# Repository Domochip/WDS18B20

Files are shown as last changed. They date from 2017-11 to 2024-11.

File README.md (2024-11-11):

# WDS18B20

This project allows you to build a wide DS18B20 sensors network **over a house**  
It uses :  

- a D1 Mini (ESP8266)
- some DS18B20 sensors
- a customized Tasmota firmware

## Build your 1-Wire bus

In order to get a wide 1-Wire bus (one that cover a house), Dallas provides some recommendations into their application note AN148.

This project use the Improved Interface bellow that is able to support a **200 meters long bus**:

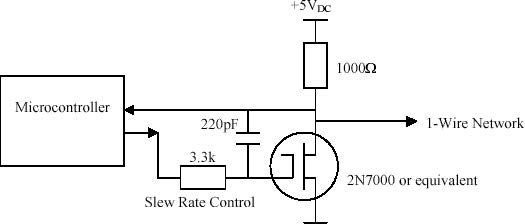
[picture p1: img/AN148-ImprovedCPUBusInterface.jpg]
Dallas AN148 ImprovedCPUBusInterface schema


This one requires a pin for reading the bus state and another one as output to drive the bus low : I named it the "Dual Pin OneWire"

**Warning : If you build a large 1 Wire bus inside your house, keep in mind that some voltage may appear on this one by induction. You need to have a good knowledge about electricity and associated risks!!!**

## Build your WDS18B20

All files are inside `schematic` subfolder and has been designed with KiCad

### Schematic

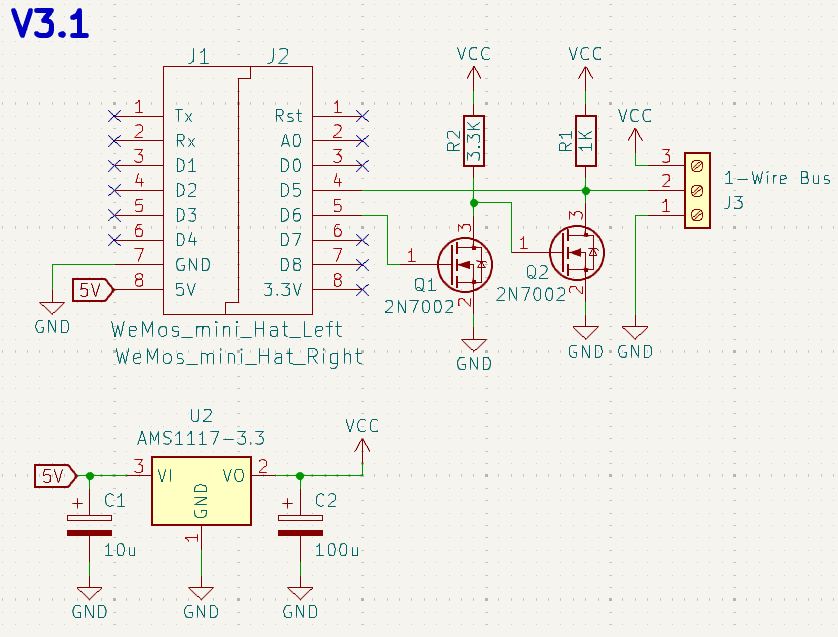
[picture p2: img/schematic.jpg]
WDS18B20 schematic


### PCB

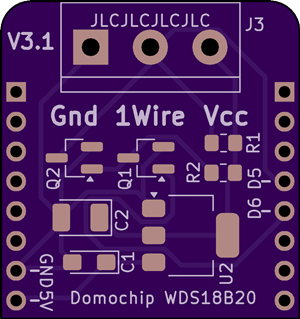
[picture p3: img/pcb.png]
WDS18B20 PCB
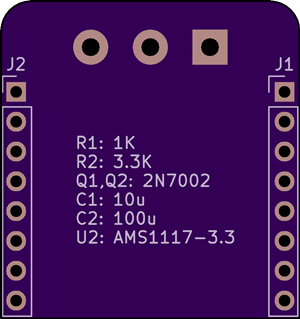
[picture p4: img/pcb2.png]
WDS18B20 PCB2


### Print your box

Box project (Fusion 360) and STL files can be found into `box` folder

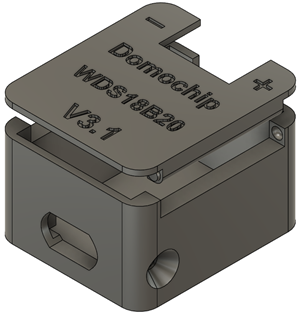
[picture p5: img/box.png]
WDS18B20 Box


## Code/Compile/Flash

A specific variation in the Tasmota code needs to be done before compilation.  
**Compile it yourself** by following bellow steps **OR precompiled binaries are available in Releases**.

### Prepare compilation environment

You need to follow Tasmota guides to be ready for compilation:  
<https://tasmota.github.io/docs/Compile-your-build/>

### Code

You need to edit `tasmota/tasmota_xsns_sensor/xsns_05_ds18x20.ino` file

1. enable `#define DS18x20_USE_ID_AS_NAME` by removing the '//'
2. replace `#define DS18X20_MAX_SENSORS  8` by `#define DS18X20_MAX_SENSORS  16`
3. For PCB 3.0 and lower
   1. replace all `digitalWrite(DS18X20Data.pin_out, HIGH);` by `digitalWrite(DS18X20Data.pin_out, newLOW);`
   2. replace all `digitalWrite(DS18X20Data.pin_out, LOW);` by `digitalWrite(DS18X20Data.pin_out, HIGH);`
   3. replace all `digitalWrite(DS18X20Data.pin_out, newLOW);` by `digitalWrite(DS18X20Data.pin_out, LOW);`
4. save
5. Compile Tasmota
6. Rename resulting tasmota.bin to tasmota-WDS18B20-12.1.0.bin

### Flash

You will find all available tools to flash tasmota in the official documentation:  
<https://tasmota.github.io/docs/Getting-Started/#needed-software>

## Run

### Tasmota Configuration

You need to apply this Template:  
`{"NAME":"WDS18B20","GPIO":[0,0,0,0,0,0,0,0,1344,0,1312,0,0,0],"FLAG":0,"BASE":18,"CMND":"Module 0|TelePeriod 60"}`

To change number of digit after the dot on reported temperatures:  
`TempRes 2`

To Enable arithmetic mean over teleperiod:  
`SetOption126 1`

For more details, please refer to the Tasmota documentation:  
<https://tasmota.github.io/docs/DS18x20>

## And finally

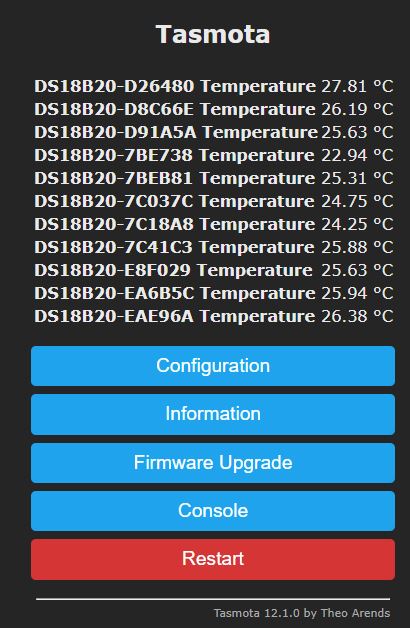
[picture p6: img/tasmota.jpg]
WDS18B20 tasmota


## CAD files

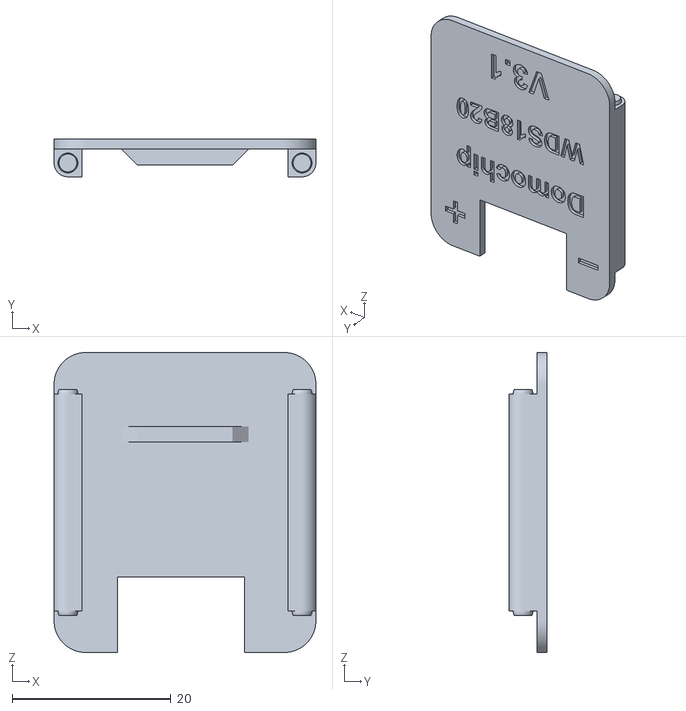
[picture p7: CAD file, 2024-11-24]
box/WDS18B20 Lid.stl
33.0 x 4.75 x 37.8

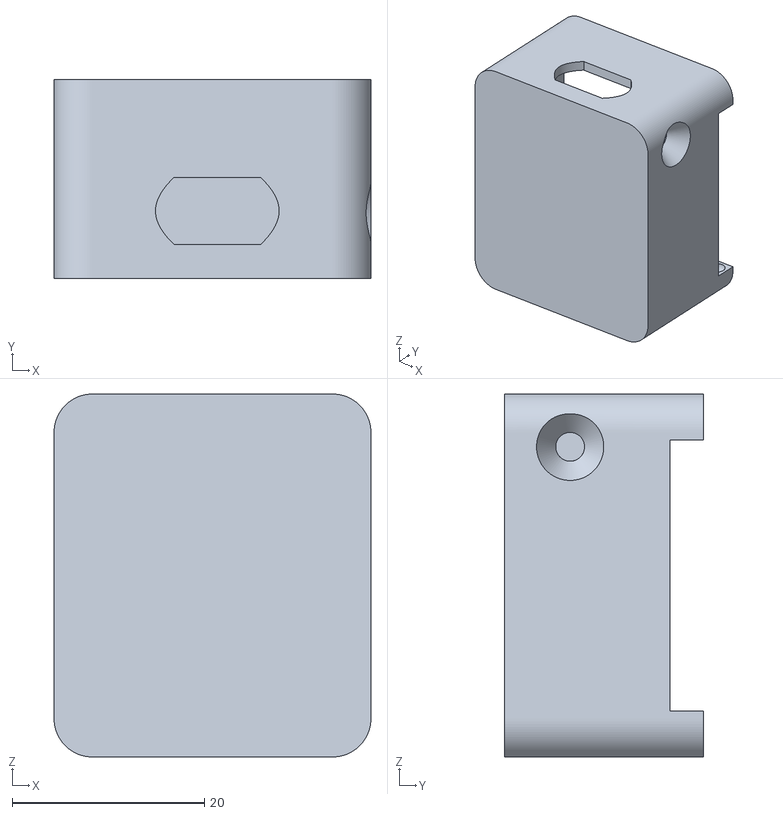
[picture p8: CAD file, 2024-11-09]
box/WDS18B20 Box.stl
33.0 x 20.8 x 37.8

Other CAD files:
box/WDS18B20 v22.f3d

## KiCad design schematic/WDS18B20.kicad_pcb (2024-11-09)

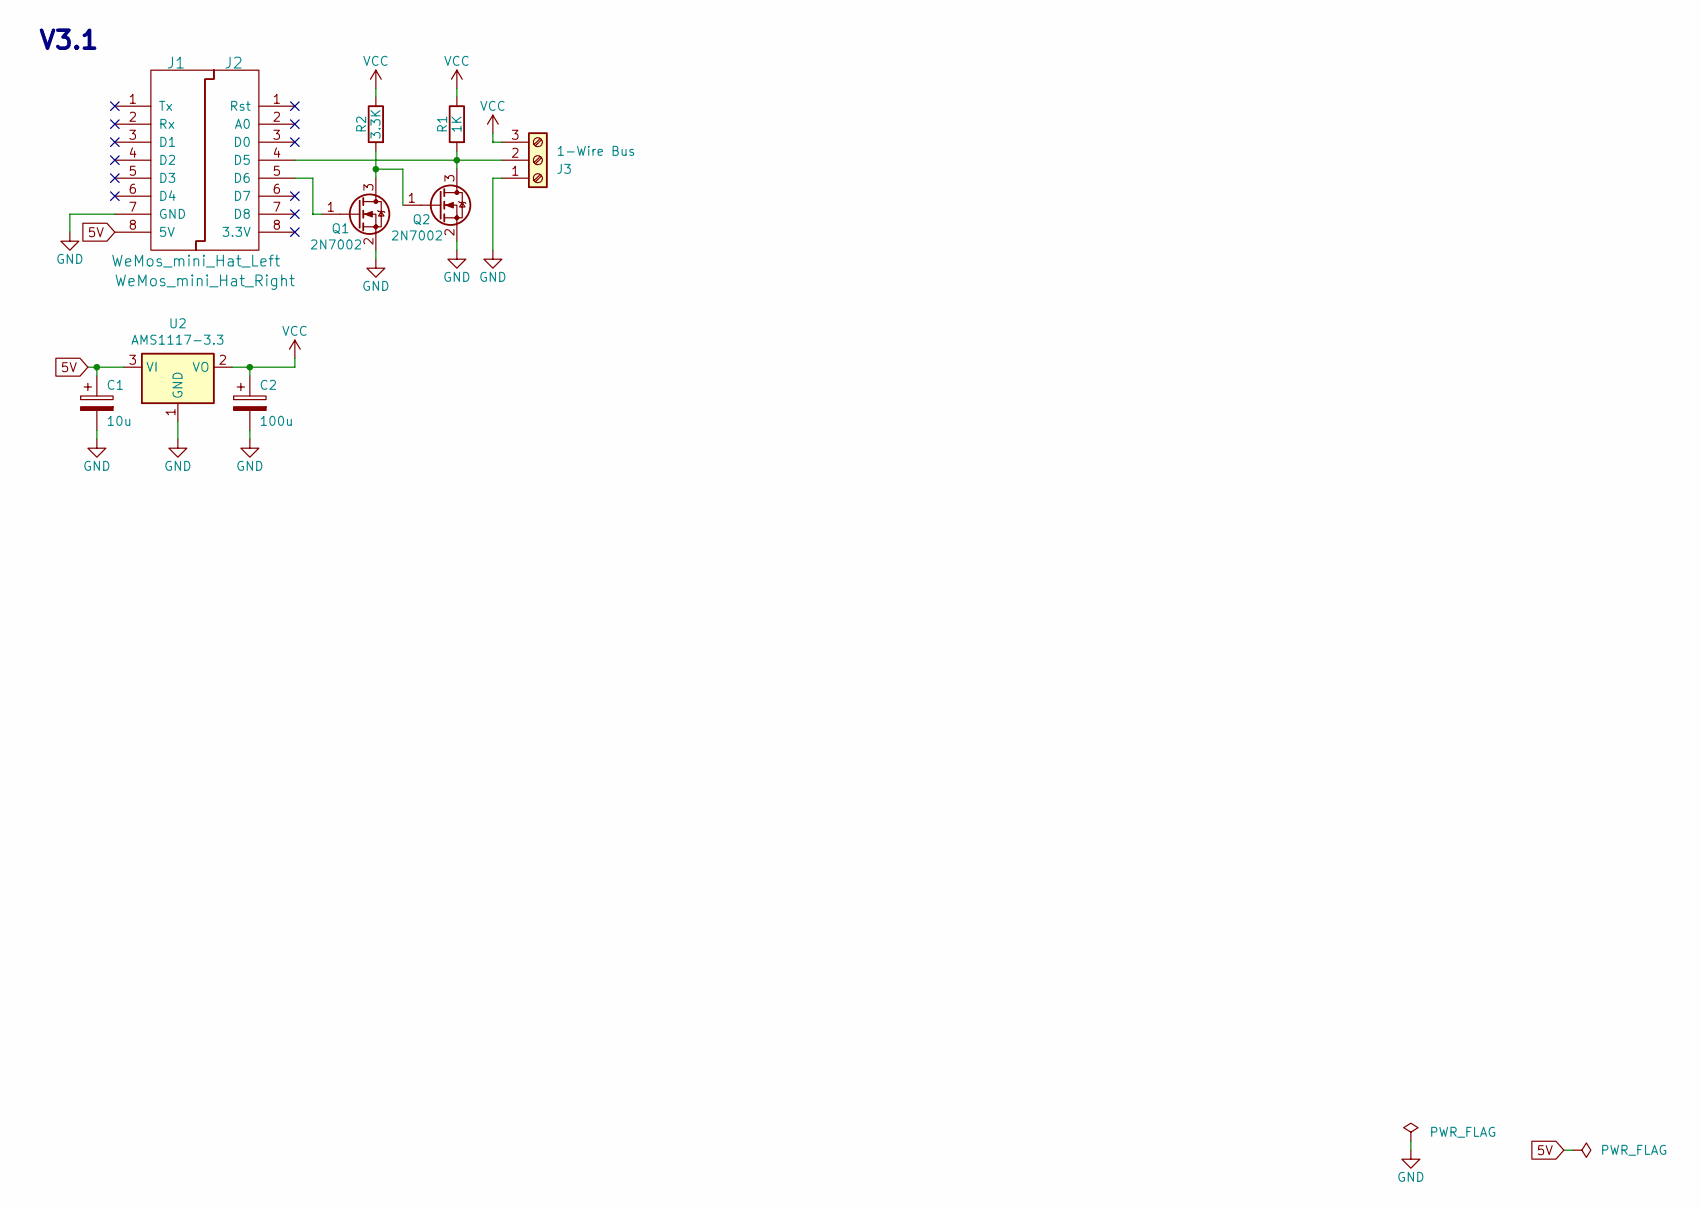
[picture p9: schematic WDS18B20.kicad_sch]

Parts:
C1: 10u; CP_EIA-3216-18_Kemet-A_Pad1.58x1.35mm_HandSolder; LCSC C7171
C2: 100u; CP_EIA-3528-21_Kemet-B_Pad1.50x2.35mm_HandSolder; LCSC C16133
J1: WeMos_mini_Hat_Left; WeMos_D1_mini_Hat_Left; LCSC C7509515
J2: WeMos_mini_Hat_Right; WeMos_D1_mini_Hat_Right; LCSC C7509515
J3: 1-Wire Bus; TerminalBlock_bornier-3_P5.08mm; LCSC C474882
Q1, Q2: 2N7002; SOT-23_Handsoldering; LCSC C8545
R1: 1K; R_0805_2012Metric_Pad1.20x1.40mm_HandSolder; LCSC C17513
R2: 3.3K; R_0805_2012Metric_Pad1.20x1.40mm_HandSolder; LCSC C26010
U2: AMS1117-3.3; SOT-223-3_TabPin2; LCSC C6186

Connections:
5V: C1.1, J1.8 (5V), U2.3 (VI)
GND: C1.2, C2.2, J1.7 (GND), J3.1, Q1.2 (S), Q2.2 (S), U2.1 (GND)
unnamed: J2.4 (D5), J3.2, Q2.3 (D), R1.2
unnamed: J2.5 (D6), Q1.1 (G)
unnamed: Q1.3 (D), Q2.1 (G), R2.2
VCC: C2.1, J3.3, R1.1, R2.1, U2.2 (VO)

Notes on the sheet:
V3.1

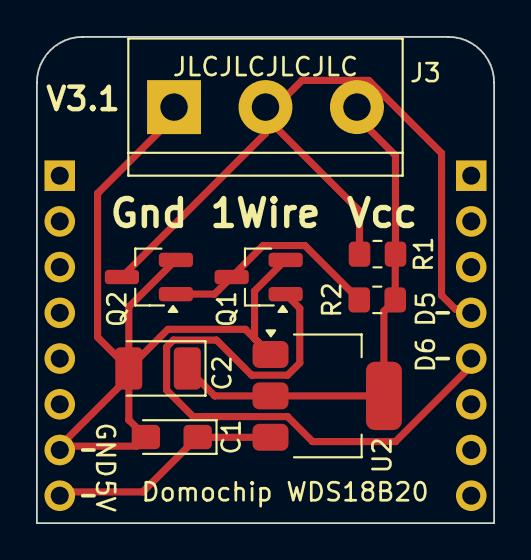
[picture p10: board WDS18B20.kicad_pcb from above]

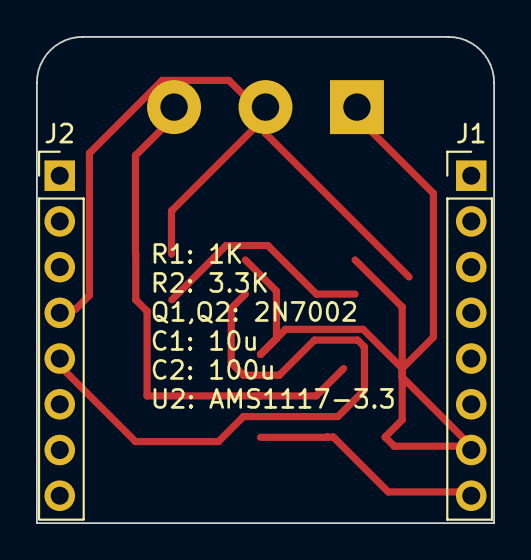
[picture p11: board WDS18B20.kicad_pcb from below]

Board: 2 copper layers, 25.4 x 27.0 mm, 10 parts (2 on the bottom side), 6 nets.

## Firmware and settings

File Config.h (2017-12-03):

#ifndef Config_h
#define Config_h

#include <ESP8266WiFi.h>
#include <ESPAsyncTCP.h>
#include <ESPAsyncWebServer.h>

#include "data\config.html.gz.h"

#define DEFAULT_AP_SSID "WirelessDS18B20"
#define DEFAULT_AP_PSK "PasswordDS"

const char predefPassword[] PROGMEM = "ewcXoCt4HHjZUvY0";

#define MAX_NUMBER_OF_BUSES 4

class Config {
  public:
    char ssid[32 + 1] = {0};
    char password[64 + 1] = {0};
    char hostname[24 + 1] = {0};
    uint32_t ip = 0;
    uint32_t gw = 0;
    uint32_t mask = 0;
    uint32_t dns1 = 0;
    uint32_t dns2 = 0;

    byte numberOfBuses = 0;
    uint8_t owBusesPins[MAX_NUMBER_OF_BUSES][2];

    void SetDefaultValues() {
      ssid[0] = 0;
      password[0] = 0;
      hostname[0] = 0;
      ip = 0;
      gw = 0;
      mask = 0;
      dns1 = 0;
      dns2 = 0;

      numberOfBuses = 0;
      memset(owBusesPins, 0, MAX_NUMBER_OF_BUSES * 2);
    }
    static byte AsciiToHex(char c); //Utils
    static bool FingerPrintS2A(byte* fingerPrintArray, const char* fingerPrintToDecode);
    static char* FingerPrintA2S(char* fpBuffer, byte* fingerPrintArray, char separator = 0);

    bool Save();
    bool Load();
    void InitWebServer(AsyncWebServer &server, bool &shouldReboot);
  private :
    String GetJSON();
    bool SetFromParameters(AsyncWebServerRequest* request);
    uint16_t crc; ///!\ crc should always stay in last position
};


#endif

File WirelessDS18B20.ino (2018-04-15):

#include <ESP8266WiFi.h>
#include <ESP8266HTTPClient.h>

#include "WirelessDS18B20.h"

//----------------------------------------------------------------------
// --- DS18B20Bus Class---
//----------------------------------------------------------------------

//-----------------------------------------------------------------------
// DS18X20 Read ScratchPad command
boolean DS18B20Bus::ReadScratchPad(byte addr[], byte data[])
{

  boolean crcScratchPadOK = false;

  //read scratchpad (if 3 failures occurs, then return the error
  for (byte i = 0; i < 3; i++)
  {
    // read scratchpad of the current device
    reset();
    select(addr);
    write(0xBE); // Read ScratchPad
    for (byte j = 0; j < 9; j++)
    { // read 9 bytes
      data[j] = read();
    }
    if (crc8(data, 8) == data[8])
    {
      crcScratchPadOK = true;
      i = 3; //end for loop
    }
  }

  return crcScratchPadOK;
}
//------------------------------------------
// DS18X20 Write ScratchPad command
void DS18B20Bus::WriteScratchPad(byte addr[], byte th, byte tl, byte cfg)
{

  reset();
  select(addr);
  write(0x4E); // Write ScratchPad
  write(th);   //Th 80°C
  write(tl);   //Tl 0°C
  write(cfg);  //Config
}
//------------------------------------------
// DS18X20 Copy ScratchPad command
void DS18B20Bus::CopyScratchPad(byte addr[])
{

  reset();
  select(addr);
  write(0x48); //Copy ScratchPad
}

//------------------------------------------
// Constructor for WebDS18B20Bus that call constructor of parent class OneWireDualPin
DS18B20Bus::DS18B20Bus(uint8_t pinIn, uint8_t pinOut) : OneWireDualPin(pinIn, pinOut){};
//------------------------------------------
// Function to initialize DS18X20 sensors
void DS18B20Bus::SetupTempSensors()
{

  byte i, j;
  byte addr[8];
  byte data[9];
  boolean scratchPadReaded;

#if ESP01_PLATFORM
  Serial.flush();
  delay(5);
  Serial.end();
#endif

  //while we find some devices
  while (search(addr))
  {

    //if ROM received is incorrect or not a DS1822 or DS18B20 THEN continue to next device
    if ((crc8(addr, 7) != addr[7]) || (addr[0] != 0x22 && addr[0] != 0x28))
      continue;

    scratchPadReaded = ReadScratchPad(addr, data);
    //if scratchPad read failed then continue to next 1-Wire device
    if (!scratchPadReaded)
      continue;

    //if config is not correct
    if (data[2] != 0x50 || data[3] != 0x00 || data[4] != 0x7F)
    {

      //write ScratchPad with Th=80°C, Tl=0°C, Config 12bits resolution
      WriteScratchPad(addr, 0x50, 0x00, 0x7F);

      scratchPadReaded = ReadScratchPad(addr, data);
      //if scratchPad read failed then continue to next 1-Wire device
      if (!scratchPadReaded)
        continue;

      //so we finally can copy scratchpad to memory
      CopyScratchPad(addr);
    }
  }
#if ESP01_PLATFORM
  Serial.begin(SERIAL_SPEED);
#endif
}
//------------------------------------------
// DS18X20 Start Temperature conversion
void DS18B20Bus::StartConvertT()
{
#if ESP01_PLATFORM
  Serial.flush();
  delay(5);
  Serial.end();
#endif

  reset();
  skip();
  write(0x44); // start conversion

#if ESP01_PLATFORM
  Serial.begin(SERIAL_SPEED);
#endif
}
//------------------------------------------
// DS18X20 Read Temperatures from all sensors
void DS18B20Bus::ReadTemperatures()
{
  //tempList will receive new list and values
  TemperatureList *tempList = new TemperatureList();

  uint8_t romCode[8];

#if ESP01_PLATFORM
  Serial.flush();
  delay(5);
  Serial.end();
#endif

  //list all romCodes
  reset_search();
  while (search(romCode))
  {

    //if ROM received is incorrect or not a Temperature sensor THEN continue to next device
    if ((crc8(romCode, 7) != romCode[7]) || (romCode[0] != 0x10 && romCode[0] != 0x22 && romCode[0] != 0x28))
      continue;

    //allocate memory
    if (!tempList->romCodes)
      tempList->romCodes = (byte(*)[8])malloc(++tempList->nbSensors * 8 * sizeof(byte));
    else
      tempList->romCodes = (byte(*)[8])realloc(tempList->romCodes, ++tempList->nbSensors * 8 * sizeof(byte));

    //copy the romCode
    for (byte i = 0; i < 8; i++)
    {
      tempList->romCodes[tempList->nbSensors - 1][i] = romCode[i];
    }
  }

  //prepare temperatures list
  tempList->temperatures = (float *)malloc(tempList->nbSensors * sizeof(float));
  byte data[12]; //buffer that receive scratchpad
  //now read all temperatures
  for (byte i = 0; i < tempList->nbSensors; i++)
  {
    //if read of scratchpad failed (3 times inside function) then put NaN in the list
    if (!ReadScratchPad(tempList->romCodes[i], data))
      tempList->temperatures[i] = (0.0 / 0.0); //NaN
    else                                       //else we were able to read data from sensor
    {

      // Convert the data to actual temperature
      // because the result is a 16 bit signed integer, it should
      // be stored to an "int16_t" type, which is always 16 bits
      // even when compiled on a 32 bit processor.
      int16_t raw = (data[1] << 8) | data[0];
      if (tempList->romCodes[i][0] == 0x10)
      {                 //type S temp Sensor
        raw = raw << 3; // 9 bit resolution default
        if (data[7] == 0x10)
        {
          // "count remain" gives full 12 bit resolution
          raw = (raw & 0xFFF0) + 12 - data[6];
        }
      }
      else
      {
        byte cfg = (data[4] & 0x60);
        // at lower res, the low bits are undefined, so let's zero them
        if (cfg == 0x00)
          raw = raw & ~7; // 9 bit resolution, 93.75 ms
        else if (cfg == 0x20)
          raw = raw & ~3; // 10 bit res, 187.5 ms
        else if (cfg == 0x40)
          raw = raw & ~1; // 11 bit res, 375 ms
        // default is 12 bit resolution, 750 ms conversion time
      }

      //final temperature is raw/16

      //return temperature
      tempList->temperatures[i] = (float)raw / 16.0;
    }
  }

#if ESP01_PLATFORM
  Serial.begin(SERIAL_SPEED);
#endif

  //Our new value list is ready
  //switch to make it available
  TemperatureList *oldList = temperatureList; //backup current one
  temperatureList = tempList;                 //make new one available

  //now we need to free memory of the old one
  if (oldList)
  {
    if (oldList->romCodes)
      free(oldList->romCodes);
    if (oldList->temperatures)
      free(oldList->temperatures);
    free(oldList);
  }
}
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

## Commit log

2017-11-26 Add Schematic and Box
    [WirelessDS18B20 v1.2.scad, WirelessDS18B20.kicad_pcb, WirelessDS18B20.sch]
2017-12-03 Switch Web Pages to new PureCSS design
2018-04-15 V3.2.1 Add MQTT and Improve Convert
    Add MQTT protocol to upload temperature regularly
    Temperature Conversion changed to a scheduled (timer in loop) system
2018-05-22 Switch to PlatfromIO
    [WirelessDS18B20 v1.2 BOM.xlsx]
2018-06-20 Switch to Base V1.0.10
2018-10-26 Switch to Base V1.1.5
2018-11-17 Switch to Base V1.1.6
    - No More PowerShell
    - GZIP and convertion to header done in python with platformIO
    - Webpages small improvement
2019-03-17 V3.2.4 Switch to D1 Mini !!! Support only one OneWire bus Upgrade to Base V1.1.7
2019-03-17 Switch schematic to D1 Mini
    [WirelessDS18B20 v1.2 BOM.xlsx, WirelessDS18B20.kicad_pcb, WirelessDS18B20.sch]
2019-03-17 Change box for D1 Mini (Use Fusion 360)
    [WirelessDS18B20 v1.2.scad, WirelessDS18B20 v3.f3d]
2019-03-26 Update Box - Add 1Wire indications
    [WirelessDS18B20 v3.f3d, WirelessDS18B20 v4.f3d]
2019-04-06 Add box in STL format
    [WirelessDS18B20 Box v4.stl, WirelessDS18B20 Lid v4.stl]
2020-01-07 Update schematic - add Optional power for large network
    [WirelessDS18B20-B_Cu.gbr, WirelessDS18B20-B_Mask.gbr, WirelessDS18B20-B_Paste.gbr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]
2020-01-12 Update schematic
    [WirelessDS18B20-B_Cu.gbr, WirelessDS18B20-B_Mask.gbr, WirelessDS18B20-B_Paste.gbr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]
2024-07-28 Update pcb
2024-10-19 Update schematic to KiCAD8
    [WirelessDS18B20.kicad_pcb, WirelessDS18B20.kicad_sch, WirelessDS18B20.sch]
2024-10-19 Add KiCad gitignore
2024-10-19 Remove useless footprints
2024-10-19 Update wemos D1 mini footprint
2024-10-19 Add PWR_FLAG to schematic
    [WirelessDS18B20.kicad_sch]
2024-10-19 V3.0 of the PCB (additional power is not optional)
    [WirelessDS18B20.kicad_pcb, WirelessDS18B20.kicad_sch]
2024-10-19 Update of schematic
    [WirelessDS18B20.kicad_pcb, WirelessDS18B20.kicad_sch]
2024-11-05 Update schematic and PCB
    [WirelessDS18B20.kicad_pcb, WirelessDS18B20.kicad_sch]
2024-11-05 Update schematic and pcb images
2024-11-05 Improve footprints
    [WirelessDS18B20.kicad_pcb]
2024-11-06 Rename KiCad Project
    [WDS18B20.kicad_pcb, WDS18B20.kicad_sch]
2024-11-09 New Box
    [WDS18B20 Box.stl, WDS18B20 Lid.stl, WDS18B20 v20.f3d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]
2024-11-11 Update box
    [WDS18B20 v20.f3d, WDS18B20 v21.f3d]
2024-11-24 Fix Lid terminal block offset
    [WDS18B20 Lid.stl, WDS18B20 v21.f3d, WDS18B20 v22.f3d]
